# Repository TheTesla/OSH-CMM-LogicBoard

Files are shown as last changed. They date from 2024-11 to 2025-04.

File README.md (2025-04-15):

# Coordinate Measurement Arm Logic Board

This logic board implements the main functionality of the 5-dof coordinate measurement arm. The central component is an _Arduino UNO R3_. It reads the rotary encoders out and provides the communication to the host PC and power supply via the USB port. 

The 5 rotary encoders are plugged into the D-Sub-9 socket. The board implements electrical protection circuits, that the _Arduino_ won't be damaged, if voltage is accidentally applied to the encoder connectors. Unfortunatelly, the  USB port can't be protected, because it is directly part of the _Aduino_.

The board also boosts the power supply voltage from the USB port to operate the rotary encoders.

## Implementation

The rotary encoders are powered by a 5 V to 9 V voltage converter, because they need at least 5 V. This lower limit is not maintained by the USB port, which can deliver down to 4.75 V.

Diodes protect the board from excessive positive voltage from the encoder connectors, while 3 transistors protect it from short circuit and negative voltage levels on the encoder supply line. The shunt _R14_ sets the current limit to around 300 mA. At this cuurent level, the b-e-voltage of _Q2_ reaches 660 mV. IN this case _Q2_ starts to disable the output transistor _Q1_. If the output voltage drops down to around 0 V, the diode _D7_ switches the transistor _Q3_ off and so also _Q1_. This reduces the output current in case of short circuit or reverse polarity voltage injection into the power supply output. Diode _D1_ protects _Q3_ against reverse voltage on the output line. 

The _Arduino_ is able to measure the output voltage to report short circuit conditions also as a self test for production end test. 

The encoder data lines are connected via 10k resistors to the _Arduino_ to protect the inputs against excessive voltage from the encoder connector.

The open collector outputs of the encoders need pull-up resistors. These are integrated into the plug of the encoder itself.

If the board is powered up, the power on indicator LED _D10_ shows the correct operation of the voltage converter. If the power supply for the rotary encoders is on, LED _D8_ lights up. For debugging and error indication, the LED _D9_ can be activated by the _Arduino_.

## Associated Projects

The rotary encoders are shipped with open wire ends. A plug has to be attached to this cable. Because there is no electrical protection in the encoder itself. it should be integrated in the plug. This project implements the protection circuit:

* https://github.com/TheTesla/rotary-encoder-protection

## Author/Contact

Stefan Helmert <stefan.helmert@htw-dresden.de>

## Appendix

### Pictures

The following pictures show the rendering of the assembled pcb. The arduino board is not available as 3d model.

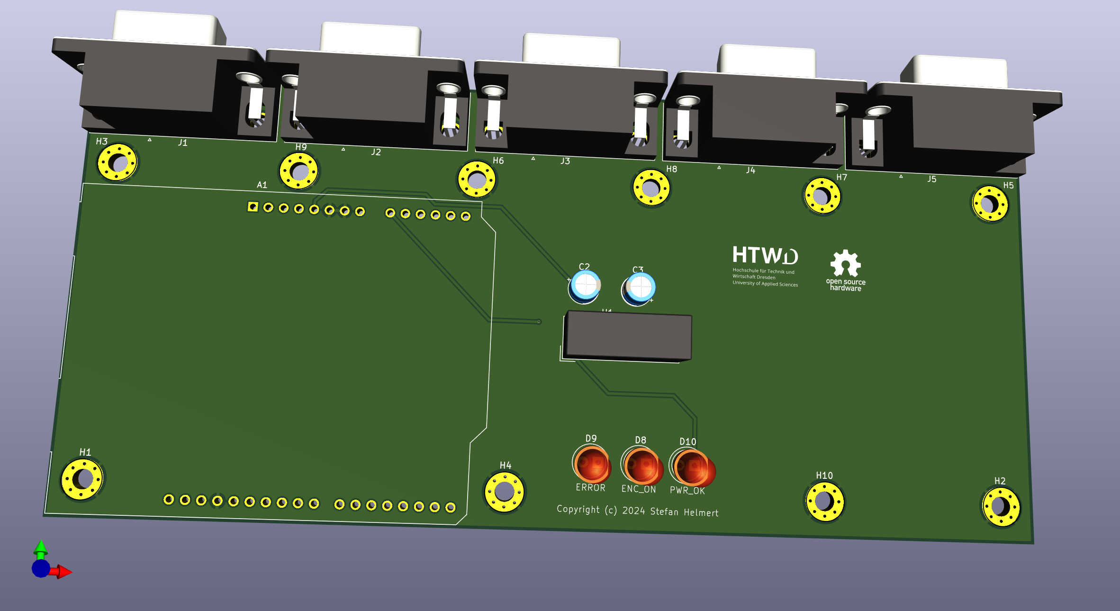
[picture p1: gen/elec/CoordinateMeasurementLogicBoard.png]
rendering of the assembled pcb, top side


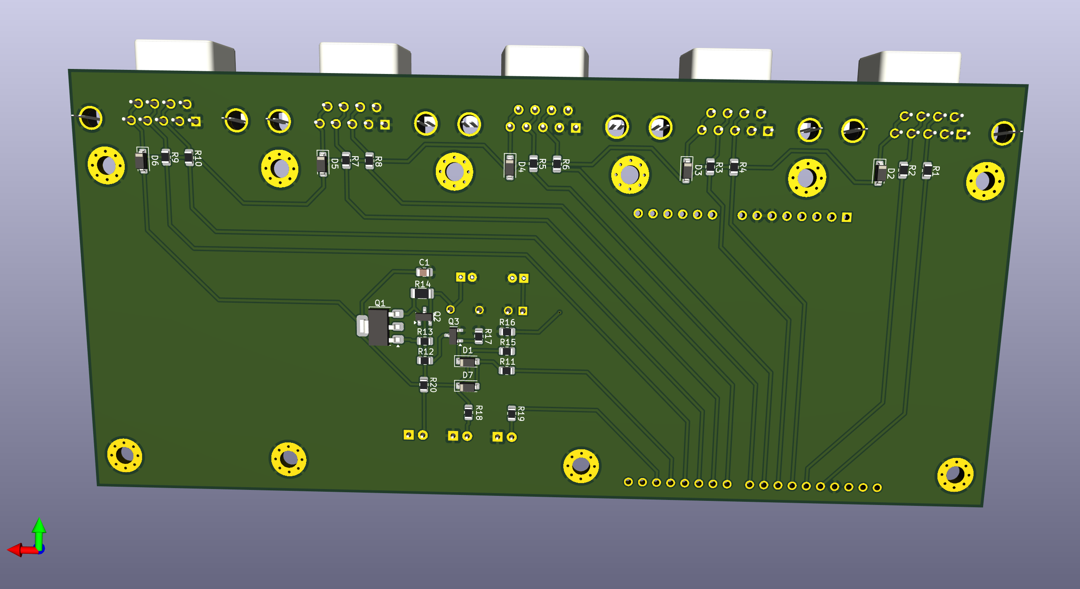
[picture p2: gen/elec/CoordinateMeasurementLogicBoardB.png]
rendering of the assembled pcb, bottom side


### Schematics

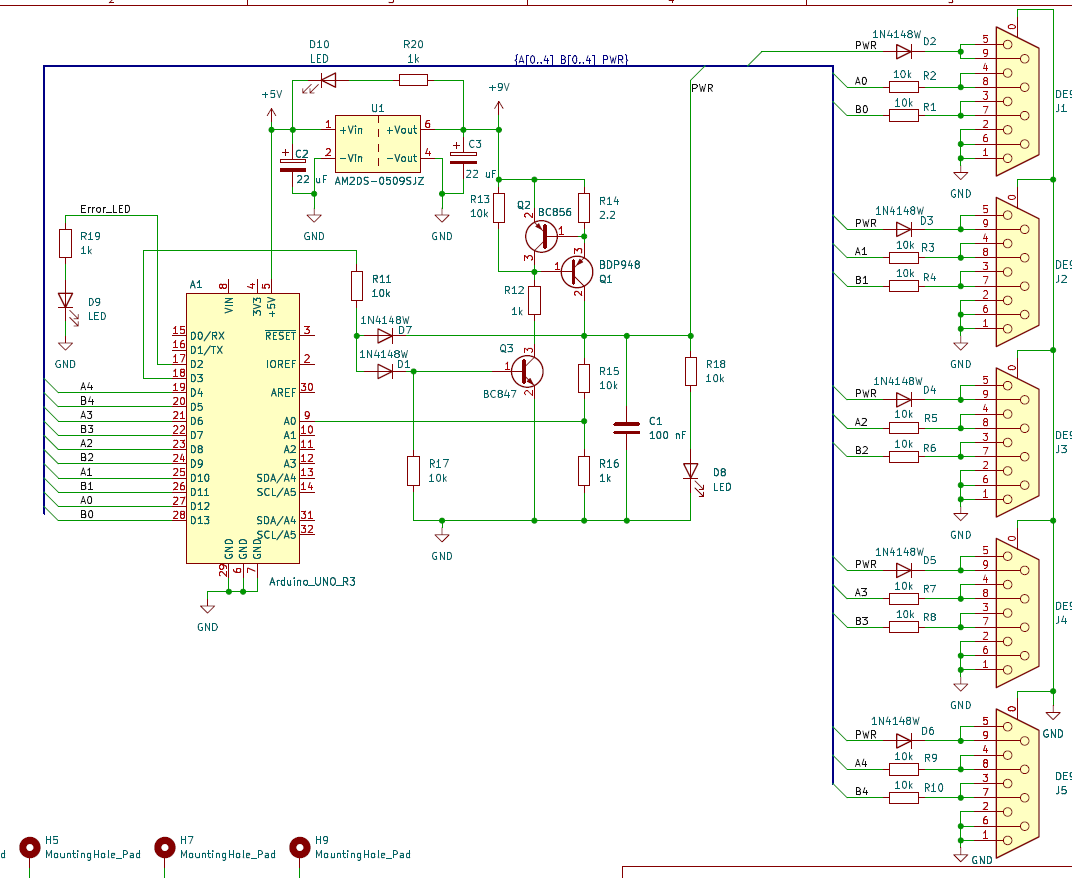
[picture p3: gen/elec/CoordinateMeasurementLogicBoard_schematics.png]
schematics


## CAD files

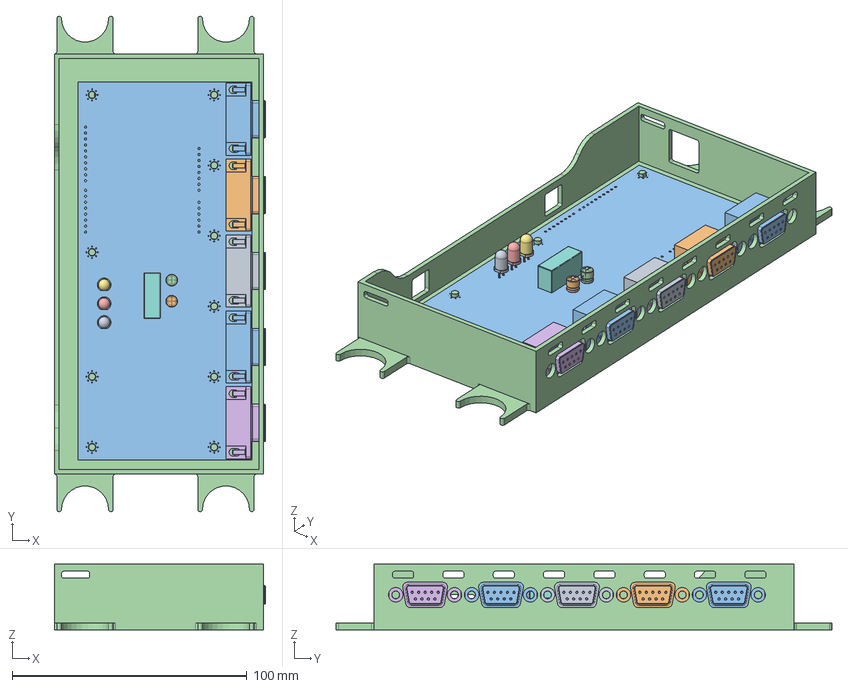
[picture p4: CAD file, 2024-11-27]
src/mech/CaseCMMLB_missing_reference.FCStd
89.8 x 211.0 x 28.0 mm
DSUB-9_Female_Horizontal_P2.77x2.84mm_EdgePinOffset4.94mm_Housed_MountingHolesOffset7.48mm
CP_Radial_D50mm_P200mm001
DSUB-9_Female_Horizontal_P2.77x2.84mm_EdgePinOffset4.94mm_Housed_MountingHolesOffset7.48mm002
CP_Radial_D50mm_P200mm002
LED_D5.0mm
DSUB-9_Female_Horizontal_P2.77x2.84mm_EdgePinOffset4.94mm_Housed_MountingHolesOffset7.48mm004
LED_D5.0mm002
Converter_DCDC_Aimtec_AM2DSxxxxSJZ_Single_THT
LED_D5.0mm004
DSUB-9_Female_Horizontal_P2.77x2.84mm_EdgePinOffset4.94mm_Housed_MountingHolesOffset7.48mm006
DSUB-9_Female_Horizontal_P2.77x2.84mm_EdgePinOffset4.94mm_Housed_MountingHolesOffset7.48mm008
R_0805_2012Metric010
SOT_223
D_SOD_124
D_SOD_125
R_0805_2012Metric012
R_0805_2012Metric014
C_0805_2012Metric002
R_0805_2012Metric016
D_SOD_126
R_0805_2012Metric018
D_SOD_127
D_SOD_128
R_0805_2012Metric020
R_0805_2012Metric022
SOT_23
R_0805_2012Metric024
R_0805_2012Metric026
R_0805_2012Metric028
R_0805_2012Metric030
R_0805_2012Metric032
R_0805_2012Metric034
D_SOD_129
R_0805_2012Metric036
R_1206_3216Metric
SOT_224
R_0805_2012Metric038
R_0805_2012Metric040
R_0805_2012Metric042
D_SOD_130
R_0805_2012Metric044
R_0805_2012Metric046
CoordinateMeasurementLogicBoard_PCB

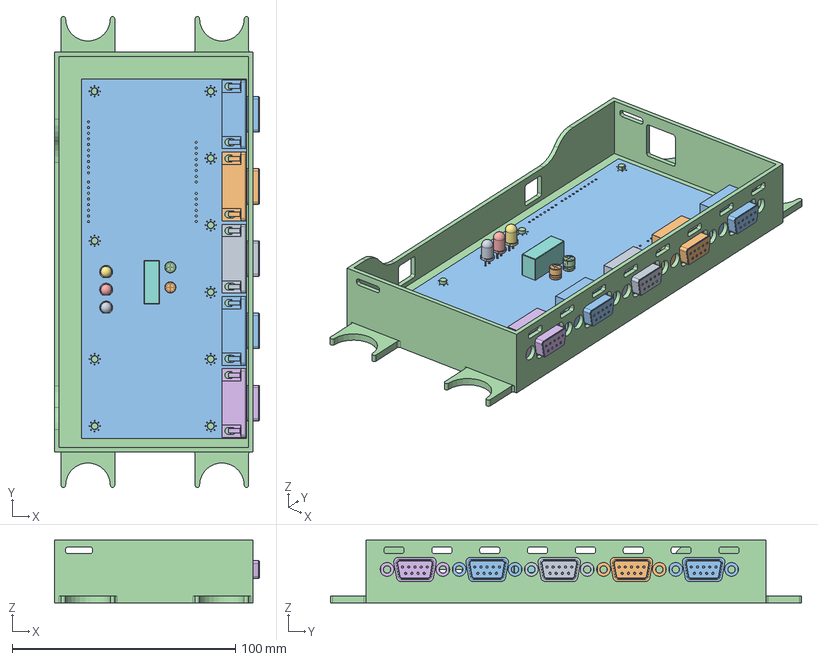
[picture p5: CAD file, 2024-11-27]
src/mech/CaseCMMLB.FCStd
91.8 x 211.0 x 28.0 mm
DSUB-9_Female_Horizontal_P2.77x2.84mm_EdgePinOffset4.94mm_Housed_MountingHolesOffset7.48mm
CP_Radial_D50mm_P200mm001
DSUB-9_Female_Horizontal_P2.77x2.84mm_EdgePinOffset4.94mm_Housed_MountingHolesOffset7.48mm002
CP_Radial_D50mm_P200mm002
LED_D5.0mm
DSUB-9_Female_Horizontal_P2.77x2.84mm_EdgePinOffset4.94mm_Housed_MountingHolesOffset7.48mm004
LED_D5.0mm002
Converter_DCDC_Aimtec_AM2DSxxxxSJZ_Single_THT
LED_D5.0mm004
DSUB-9_Female_Horizontal_P2.77x2.84mm_EdgePinOffset4.94mm_Housed_MountingHolesOffset7.48mm006
DSUB-9_Female_Horizontal_P2.77x2.84mm_EdgePinOffset4.94mm_Housed_MountingHolesOffset7.48mm008
R_0805_2012Metric010
SOT_223
D_SOD_124
D_SOD_125
R_0805_2012Metric012
R_0805_2012Metric014
C_0805_2012Metric002
R_0805_2012Metric016
D_SOD_126
R_0805_2012Metric018
D_SOD_127
D_SOD_128
R_0805_2012Metric020
R_0805_2012Metric022
SOT_23
R_0805_2012Metric024
R_0805_2012Metric026
R_0805_2012Metric028
R_0805_2012Metric030
R_0805_2012Metric032
R_0805_2012Metric034
D_SOD_129
R_0805_2012Metric036
R_1206_3216Metric
SOT_224
R_0805_2012Metric038
R_0805_2012Metric040
R_0805_2012Metric042
D_SOD_130
R_0805_2012Metric044
R_0805_2012Metric046
CoordinateMeasurementLogicBoard_PCB

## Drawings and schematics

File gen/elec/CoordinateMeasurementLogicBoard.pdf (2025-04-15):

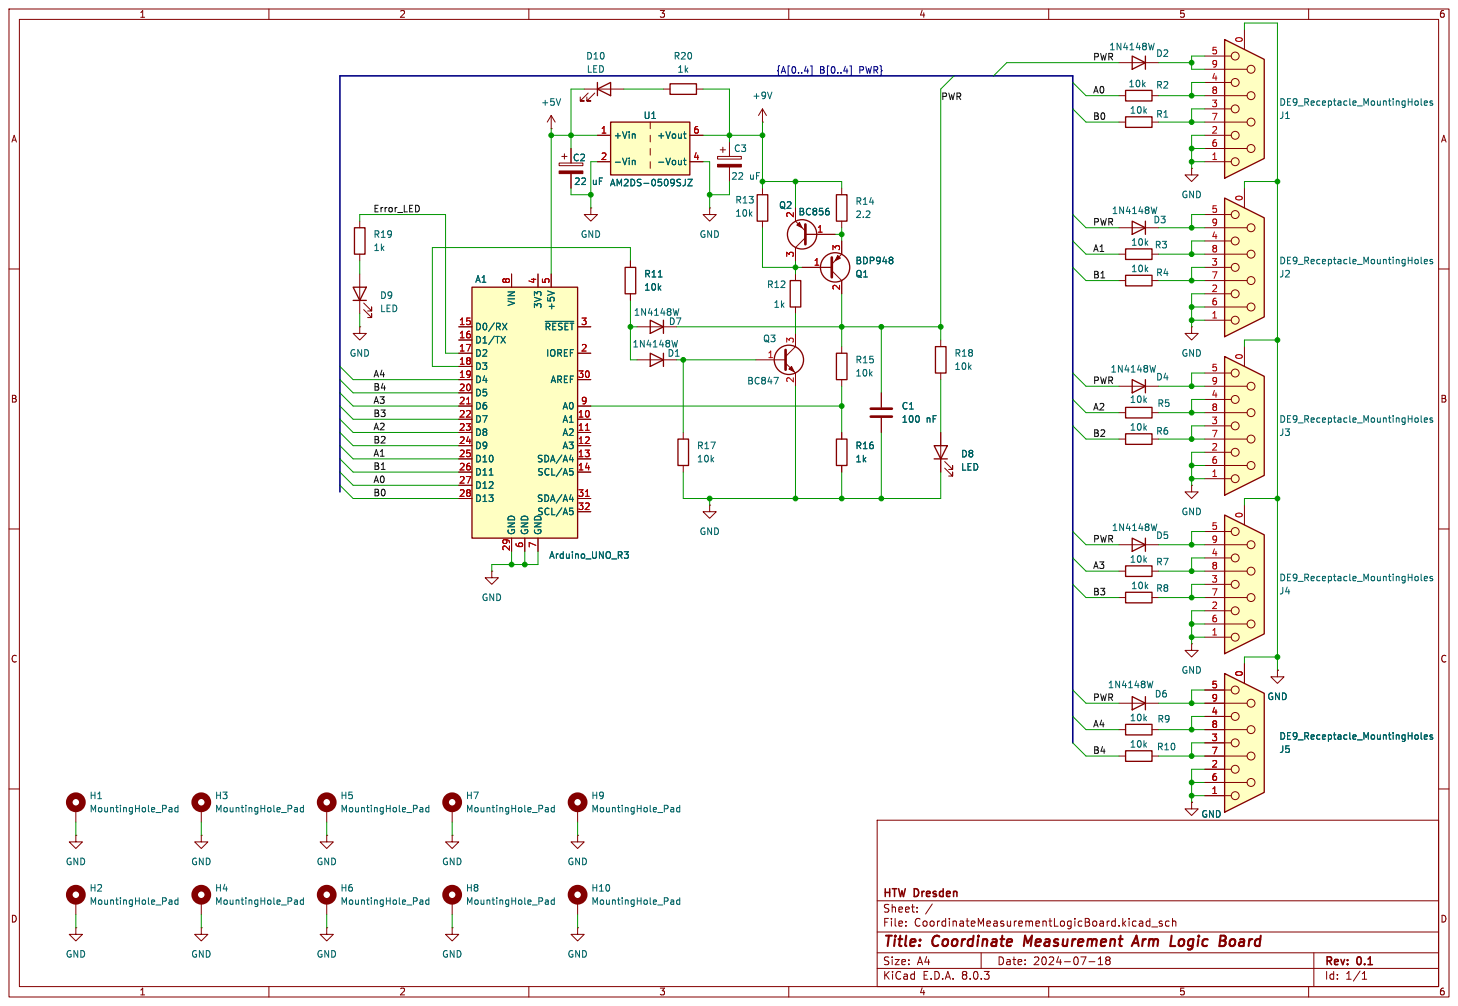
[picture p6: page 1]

2 3 A1 Arduino_UNO_R3 A1 10 A2 11 A3 12 SDA/A4 13 SCL/A5 14 D0/RX 15 D1/TX 16 D2 17 D3 18 D4 19
~{RESET}3 AREF 30 SDA/A4 31 SCL/A5 32 3V3

10k GND

Id: 1/1 Title: Coordinate Measurement Arm Logic Board

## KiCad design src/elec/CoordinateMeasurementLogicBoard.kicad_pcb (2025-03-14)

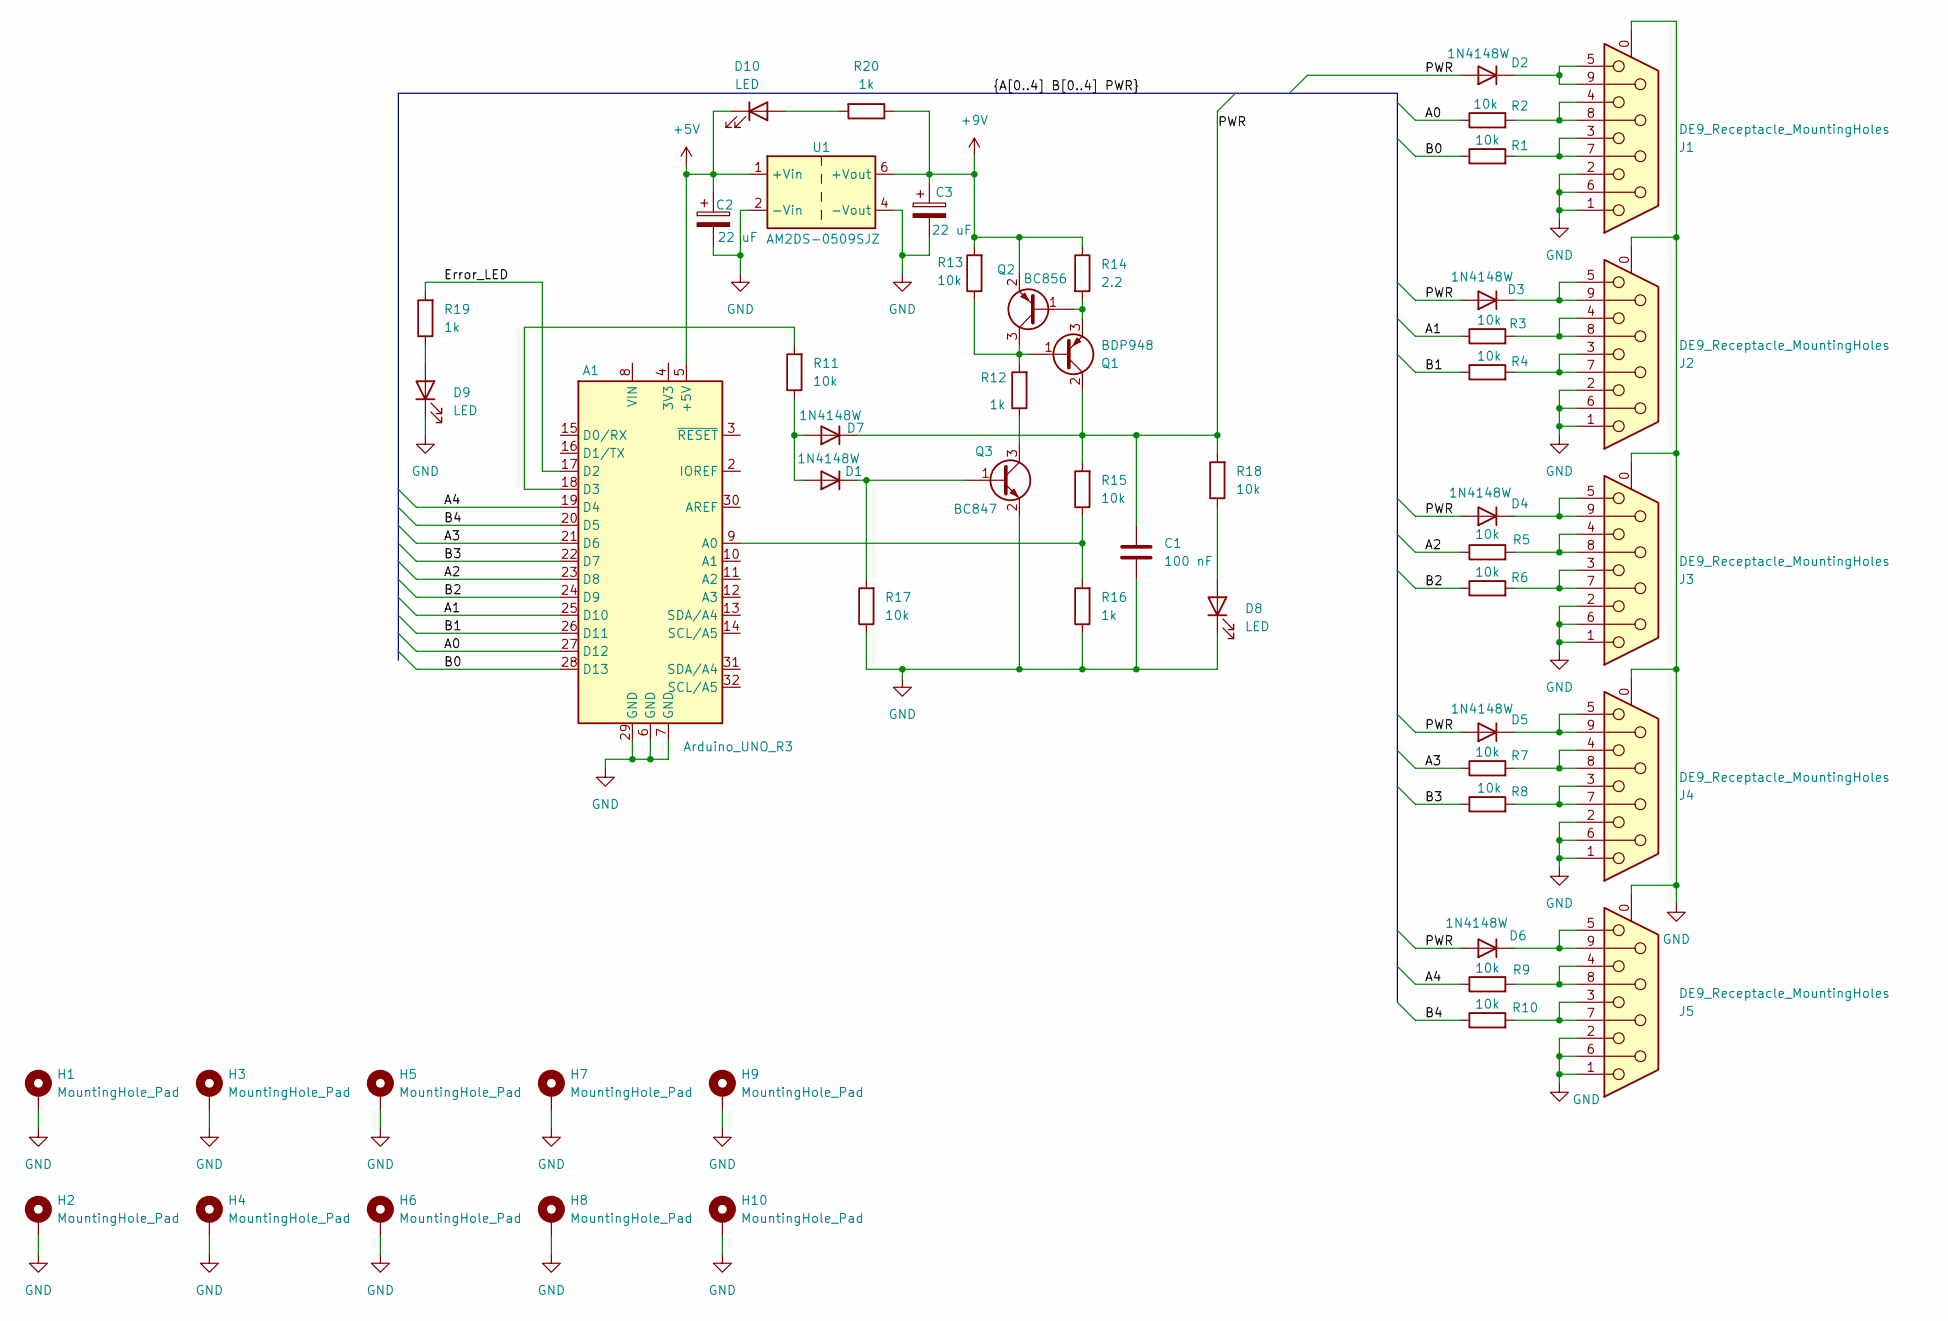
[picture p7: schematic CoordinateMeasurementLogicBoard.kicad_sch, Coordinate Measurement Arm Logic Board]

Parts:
A1: Arduino_UNO_R3
C1: 100 nF; C_0805_2012Metric
C2, C3: 22 uF; CP_Radial_D5.0mm_P2.00mm
D1, D2, D3, D4, D5, D6, D7: 1N4148W; D_SOD-123
D8, D9, D10: LED; LED_D5.0mm
H1, H2, H3, H4, H5, H6, H7, H8, H9, H10: MountingHole_Pad; MountingHole_3.2mm_M3_Pad_Via
J1, J2, J3, J4, J5: DE9_Receptacle_MountingHoles; DSUB-9_Socket_Horizontal_P2.77x2.84mm_EdgePinOffset7.70mm_H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
Q1: BDP948; SOT-223-3_TabPin2
Q2: BC856; SOT-23
Q3: BC847; SOT-23
R1, R2, R3, R4, R5, R6, R7, R8, R9, R10, R11, R13, R15, R17, R18: 10k; R_0805_2012Metric
R12, R16, R19, R20: 1k; R_0805_2012Metric
R14: 2.2; R_1206_3216Metric
U1: AM2DS-0509SJZ; Converter_DCDC_Aimtec_AM2DS-xxxxSJZ_Single_THT

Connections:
+5V: A1.5 (+5V), C2.1, D10.1 (K), U1.1 (+Vin)
+9V: C3.1, Q2.2 (E), R13.2, R14.1, R20.1, U1.6 (+Vout)
/A0: A1.27 (D12), R2.1
/A1: A1.25 (D10), R3.1
/A2: A1.23 (D8), R5.1
/A3: A1.21 (D6), R7.1
/A4: A1.19 (D4), R9.1
/B0: A1.28 (D13), R1.1
/B1: A1.26 (D11), R4.1
/B2: A1.24 (D9), R6.1
/B3: A1.22 (D7), R8.1
/B4: A1.20 (D5), R10.1
/Error_LED: A1.17 (D2), R19.2
/PWR: C1.1, D2.2 (A), D3.2 (A), D4.2 (A), D5.2 (A), D6.2 (A), D7.1 (K), Q1.2 (C), Q1.4 (C), R15.2, R18.2
GND: A1.6 (GND), A1.7 (GND), A1.29 (GND), C1.2, C2.2, C3.2, D8.1 (K), D9.1 (K), H1.1, H2.1, H3.1, H4.1, H5.1, H6.1, H7.1, H8.1, H9.1, H10.1, J1.0 (PAD), J1.1, J1.2, J1.6, J2.0 (PAD), J2.1, J2.2, J2.6, J3.0 (PAD), J3.1, J3.2, J3.6, J4.0 (PAD), J4.1, J4.2, J4.6, J5.0 (PAD), J5.1, J5.2, J5.6, Q3.2 (E), R16.1, R17.1, U1.2 (-Vin), U1.4 (-Vout)
unnamed: A1.9 (A0), R15.1, R16.2
unnamed: A1.18 (D3), R11.2
unnamed: D1.2 (A), D7.2 (A), R11.1
unnamed: D1.1 (K), Q3.1 (B), R17.2
unnamed: D2.1 (K), J1.5, J1.9
unnamed: D3.1 (K), J2.5, J2.9
unnamed: D4.1 (K), J3.5, J3.9
unnamed: D5.1 (K), J4.5, J4.9
unnamed: D6.1 (K), J5.5, J5.9
unnamed: D8.2 (A), R18.1
unnamed: D9.2 (A), R19.1
unnamed: D10.2 (A), R20.2
unnamed: J1.3, J1.7, R1.2
unnamed: J1.4, J1.8, R2.2
unnamed: J2.3, J2.7, R4.2
unnamed: J2.4, J2.8, R3.2
unnamed: J3.3, J3.7, R6.2
unnamed: J3.4, J3.8, R5.2
unnamed: J4.3, J4.7, R8.2
unnamed: J4.4, J4.8, R7.2
unnamed: J5.3, J5.7, R10.2
unnamed: J5.4, J5.8, R9.2
unnamed: Q1.1 (B), Q2.3 (C), R12.2, R13.1
unnamed: Q1.3 (E), Q2.1 (B), R14.2
unnamed: Q3.3 (C), R12.1

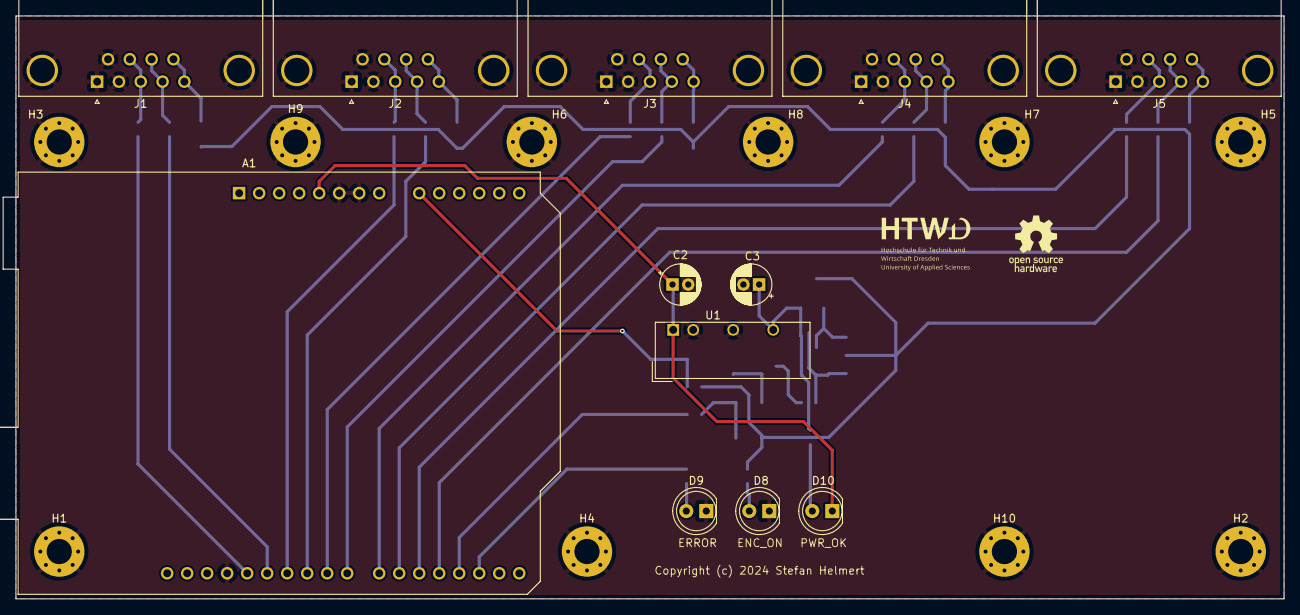
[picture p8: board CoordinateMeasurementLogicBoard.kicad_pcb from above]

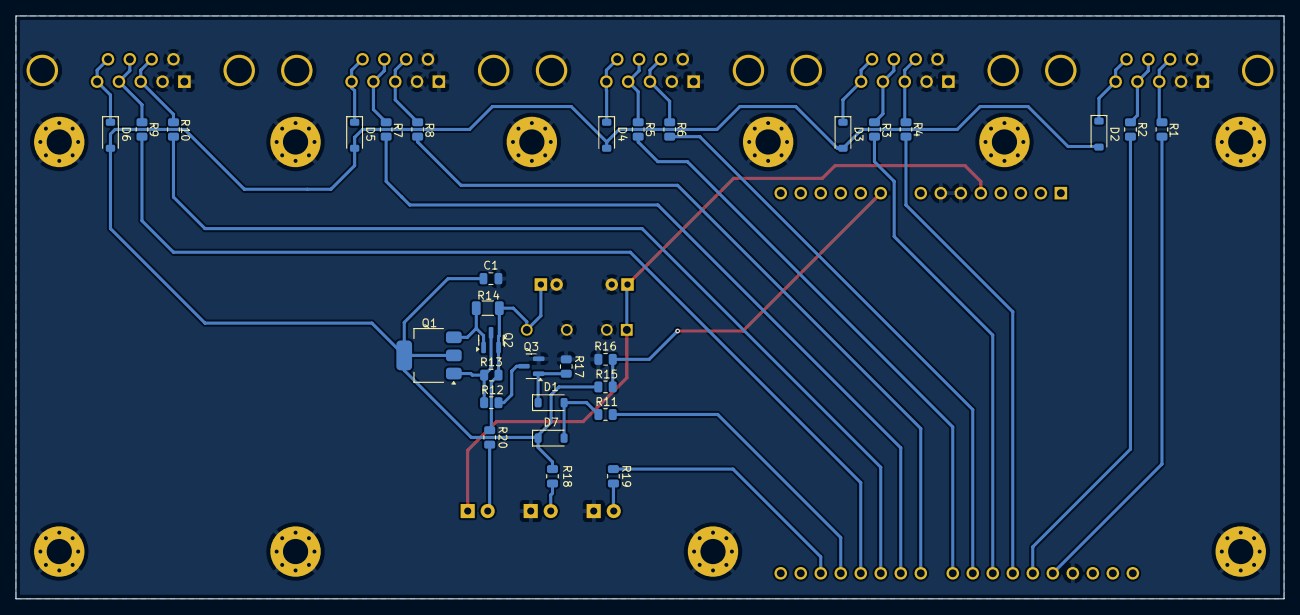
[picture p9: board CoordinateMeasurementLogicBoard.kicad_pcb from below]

Board: 2 copper layers, 161.0 x 74.0 mm, 53 parts (31 on the bottom side), 40 nets.

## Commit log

2024-07-11 added symbol, footprint and 3d model for DCDC converter; mostly ready schematic
    [CoordinateMeasurementLogicBoard.kicad_pcb, CoordinateMeasurementLogicBoard.kicad_sch]
2024-07-11 one protection circuit for all encoders; todo: select 2.2 ohm shunt, add caps for step up, LEDs
    [CoordinateMeasurementLogicBoard.kicad_sch]
2024-07-12 one protection for all encoders; protection end transistor with 5 W, shunt 0.25 W; caps for dcdc converter
    [CoordinateMeasurementLogicBoard.kicad_sch]
2024-07-17 fix: voltage divider; board nearly ready
    [CoordinateMeasurementLogicBoard.kicad_pcb, CoordinateMeasurementLogicBoard.kicad_sch]
2024-07-17 optimized silkscreen; todo: added mounting holes, HTW logo and copyright
    [CoordinateMeasurementLogicBoard.kicad_pcb]
2024-07-17 fix: R16 wasn't updated correctly
    [CoordinateMeasurementLogicBoard.kicad_pcb, CoordinateMeasurementLogicBoard.kicad_sch]
2024-07-18 ready; mounting holes; cosmetic
    [CoordinateMeasurementLogicBoard.kicad_pcb, CoordinateMeasurementLogicBoard.kicad_sch]
2024-11-25 start case in FreeCAD
    [CaseCMMLB.FCStd]
2024-11-26 logic board case nearly ready
    [CaseCMMLB.FCStd]
2024-11-27 PCB fits better
    [CaseCMMLB.FCStd, CaseCMMLB_missing_reference.FCStd]
2024-11-28 case top ready
    [CaseCMMLB_missing_reference_test.FCStd]
2024-11-28 removed stl
2025-03-14 replaced D-Sub-9 Connector
    [CoordinateMeasurementLogicBoard.kicad_pcb, CoordinateMeasurementLogicBoard.kicad_sch]
2025-04-15 repo structure like OSH design guide
    [CaseCMMLB.FCStd, CaseCMMLB_missing_reference.FCStd, CaseCMMLB_missing_reference_test.FCStd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]

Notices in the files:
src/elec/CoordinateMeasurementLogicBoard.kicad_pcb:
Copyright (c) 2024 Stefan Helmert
